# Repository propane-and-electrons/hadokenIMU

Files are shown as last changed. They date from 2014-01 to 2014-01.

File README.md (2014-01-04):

hadokenIMU
----------

hadokenIMU is an Arduino Leonardo compatible 9DoF inertial measurement unit (IMU) with integrated LiPo battery charger and XBee-style radio connector. The name was chosen because these boards are an integrated design for gesture recognition gloves for Super Street Fire: live action Street Fighter 2 in a ring of fire.

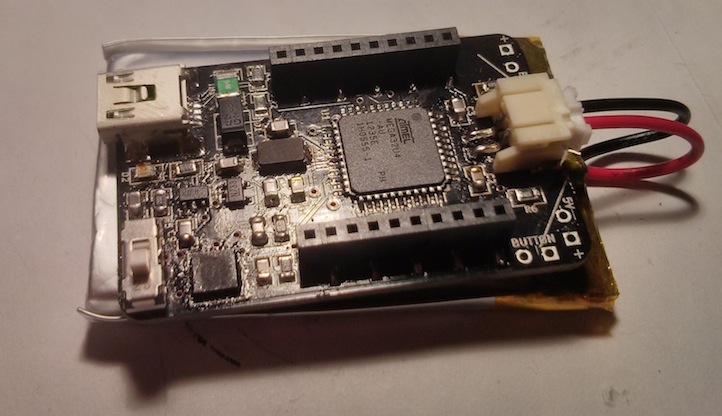
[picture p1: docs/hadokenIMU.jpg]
hadokenIMU photo


### Feature Summary

* Arduino Leonardo compatible
* Programmable via Mini USB jack or 6-pin ICSP header using pogo pins
* Wireless support with [RN-XV WiFly](http://rovingnetworks.com/products/RN171XV), Bluetooth Bee, or compatible radio
* Uses an [Invensense MPU-9150](http://www.invensense.com/mems/gyro/mpu9150.html) 9DoF sensor for 3-axis accelerometer, gyroscope, and magnetometer data over I2C
* Battery power provided through a 2-pin JST header
* LiPo charging circuitry integrated - charge off USB connection
* Optional button connector for output trigger
* 1.15" x 1.8" - slightly smaller than a 1000mAh LiPo battery

### Documents

* [Schematic](docs/hadokenIMU-schematic.pdf)
* [Bill of Materials](docs/hadokenIMU-BOM.csv)

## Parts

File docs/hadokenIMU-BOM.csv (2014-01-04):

Designator | Package | Quantity | Part | Digi-Key Part
C1,C4 | SM0805 | 2 | 22pF | 399-5568-1-ND
C2,C6,C9 | SM0805 | 3 | 0.1uF | 445-7534-1-ND
C3 | SM0805 | 1 | 1uF | 445-1358-1-ND
C5,C8 | SM0805 | 2 | 4.7uF | 445-1605-1-ND
C7 | SM0805 | 1 | 10uF | 445-6857-1-ND
C10 | SM0805 | 1 | 2.2nF | 399-5327-1-ND
D1 | DO214 | 1 | GF1A | GF1A-E3/67AGICT-ND
D2 | SM0805 | 1 | LED (blue) | 160-1645-1-ND
J1 | USB-M26FTR | 1 | USB Mini header | ED2992CT-ND
M1 | XBEE-SMD | 1 | RN-XV | 740-1044-ND
P2 | JST-2-SMD | 1 | JST-2 header | 455-1749-1-ND
R1,R2 | SM0805 | 2 | 22 | P22.0CCT-ND
R3 | SM0805 | 1 | 470 | P470ACT-ND
R4,R6 | SM0805 | 2 | 10k | P10KACT-ND
R5 | SM0805 | 1 | 2k | P2.0KACT-ND
R7,R8 | SM0805 | 2 | 4.7k | P4.7KACT-ND
SW1 | CL-SB-12A | 1 | SPST switch | 563-1314-1-ND
TH1 | SM1210 | 1 | 0ZCB0050FF2G | 507-1489-1-ND
U1 | TQFP44 | 1 | ATMEGA32U4 | ATMEGA32U4-AU-ND
U2 | TSOT23-5 | 1 | MIC5265 | 576-2835-1-ND
U3 | SOT23-5 | 1 | MCP73831 | MCP73831T-2ACI/OTCT-ND
U4 | QFN24 | 1 | MPU-9150 | 1428-1009-1-ND
X1 | NX5032GA | 1 | NX5032GA | 644-1037-1-ND
XM1A, XM1B | 10PIN 2MM SMD | 2 | NPPN101BFLD-RC | S5902-10-ND

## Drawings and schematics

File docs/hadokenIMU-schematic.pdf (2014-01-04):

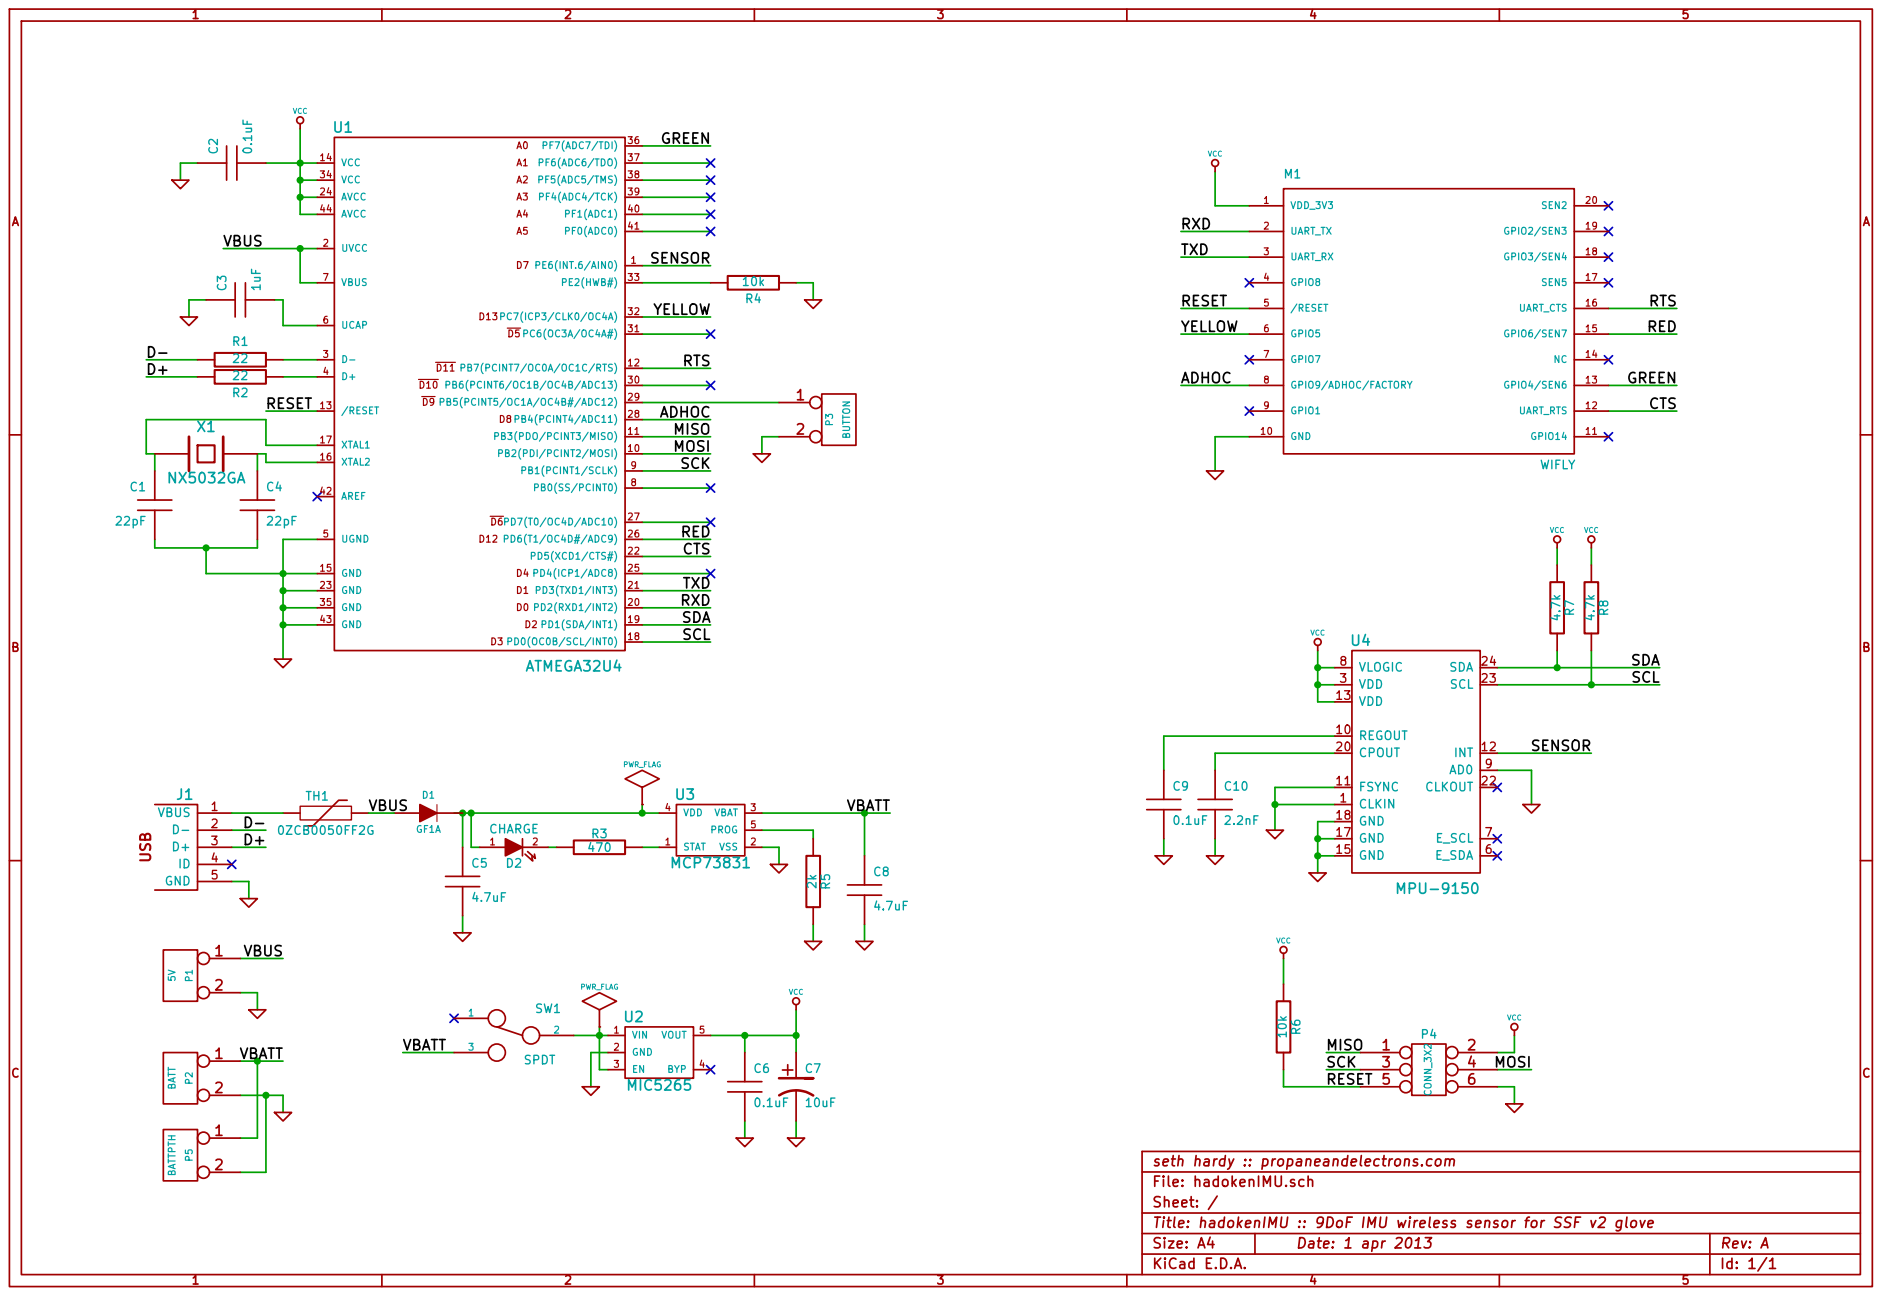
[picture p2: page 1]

Title: hadokenIMU :: 9DoF IMU wireless sensor for SSF v2 glove File: hadokenIMU.sch Sheet: /

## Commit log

2013-03-09 initial commit after board tested and working
    [hadokenIMU.brd, hadokenIMU.sch]
2013-03-10 picked a name
    [hadokenIMU.brd]
2013-04-01 fixed bug with PTC/diode/vbus, looks like the board is now using the new file format
    [hadokenIMU.brd, hadokenIMU.sch]
2013-04-01 fixed bug with PTC/diode/vbus
    [hadokenIMU.brd, hadokenIMU.sch]
2013-04-24 adding rounded corners
    [hadokenIMU.brd]
2013-04-27 adding gyro and accel axis labeling
    [hadokenIMU.brd]
2014-01-04 adding BOM
    [hadokenIMU-BOM.csv]
2014-01-04 updating BOM
    [hadokenIMU-BOM.csv]
2014-01-16 fixing footprint names
    [hadokenIMU.brd]
